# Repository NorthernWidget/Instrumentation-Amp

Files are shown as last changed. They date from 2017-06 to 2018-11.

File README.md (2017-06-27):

# Instrumentation-Amp

Breakout board for the AD623 instrumentation amplifier.

It is set up to work in either single-supply or dual-supply mode

## Single-supply mode

* Connect VC- (negative supply voltage) to GND using JP_VC- or the screw terminals

For sensors that require a simple common ground (including the reference), you will close the circuit across all of the solder jumpers:
* Connect VS- (negative voltage from device with signal to be amplified) to GND using JP_VS- or the screw terminals
* Connect Vref (reference voltage for the input signal) to GND using JP_VREF or the screw terminals

We use connect all of the jumpers to use a pyranometer.

### Dual-supply mode

We haven't had to use the board this way, but set it up to work!

* Disconnect VC- (negative supply voltage) from GND: check JP_VC- and the screw terminals
* Disconnect VS- (negative voltage from device with signal to be amplified) from GND: check JP_VS- and the screw terminals

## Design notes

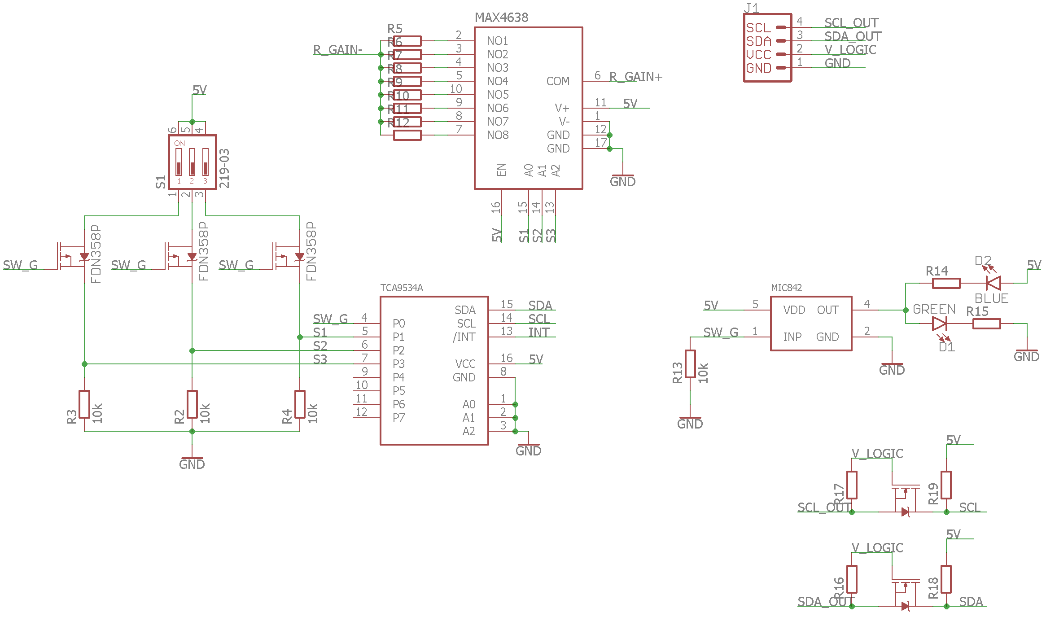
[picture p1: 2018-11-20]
PopulationDoc_pg2.png

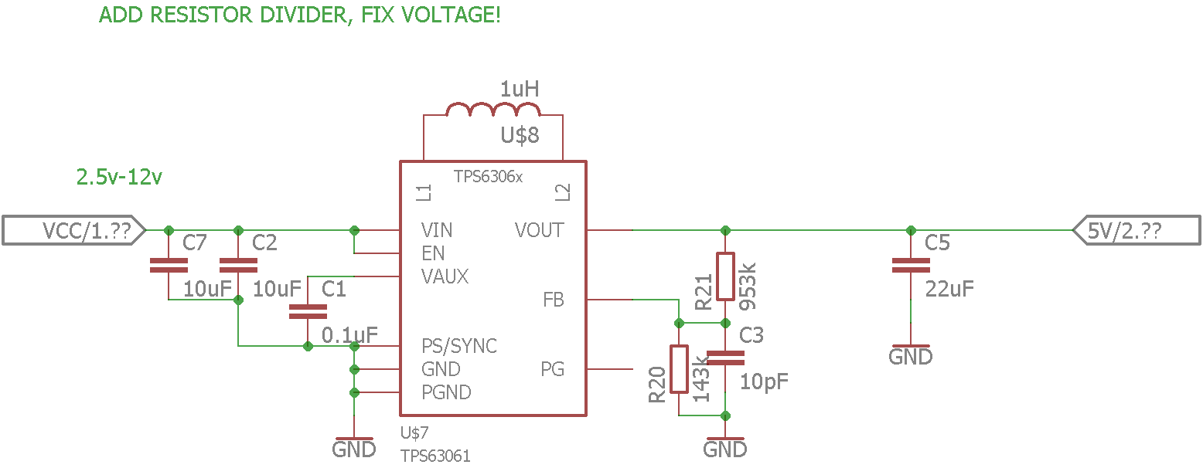
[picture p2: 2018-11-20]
PopulationDoc_pg3.png

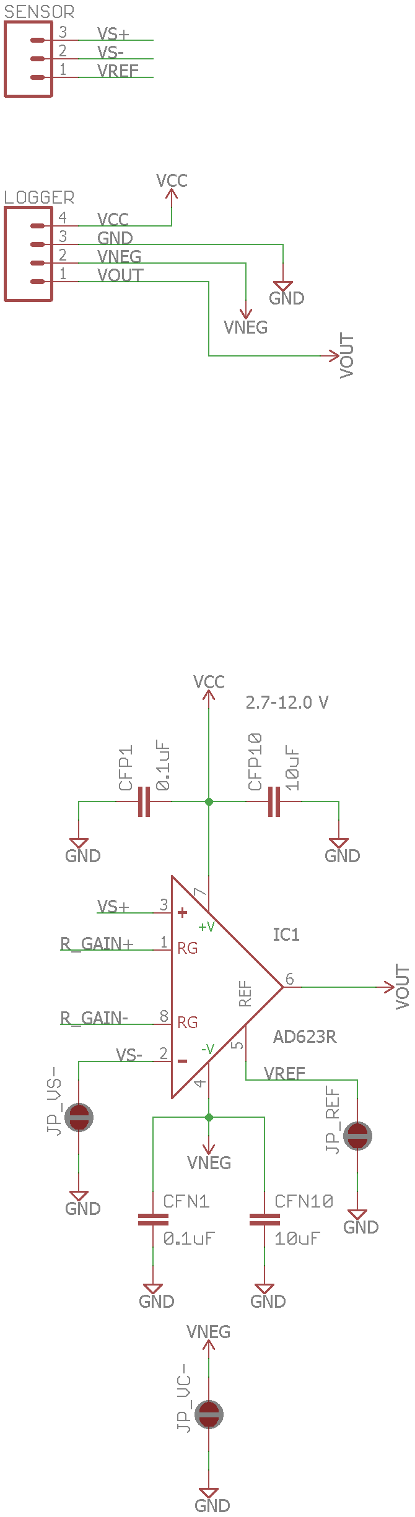
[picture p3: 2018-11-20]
PopulationDoc.png

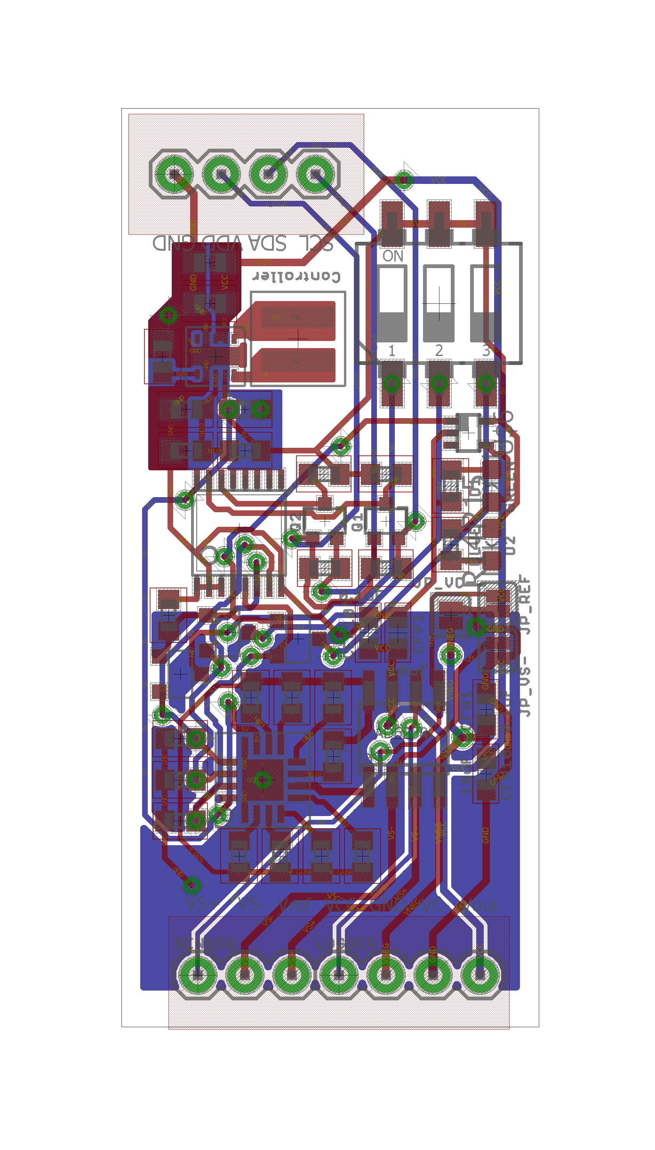
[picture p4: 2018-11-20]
PopulationBoard.png

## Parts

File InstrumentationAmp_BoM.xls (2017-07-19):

Part Number (Digi-Key) | Description | Customer Reference | Available Quantity | Backorder Quantity | Unit Price | Extended Price | Notes
AD623ARZ-RLCT-ND | IC OPAMP INSTR 800KHZ RRO 8SOIC | INSTRUMENTATION AMP | 1 | 0 | 4.55 | 4.55
 |  | Cap 10 uF 0603 | 2 | 0 |  |  | >=50V
 |  | Cap 0.1 uF 0603 | 2 | 0 |  |  | >=50V
 |  | Screw Terminal x2 0.1” |  |  |  |  | OPTIONAL
 |  | Screw Terminal x4 0.1” |  |  |  |  | OPTIONAL
 |  | Gain Resistor |  |  |  |  | USER-SELECTED

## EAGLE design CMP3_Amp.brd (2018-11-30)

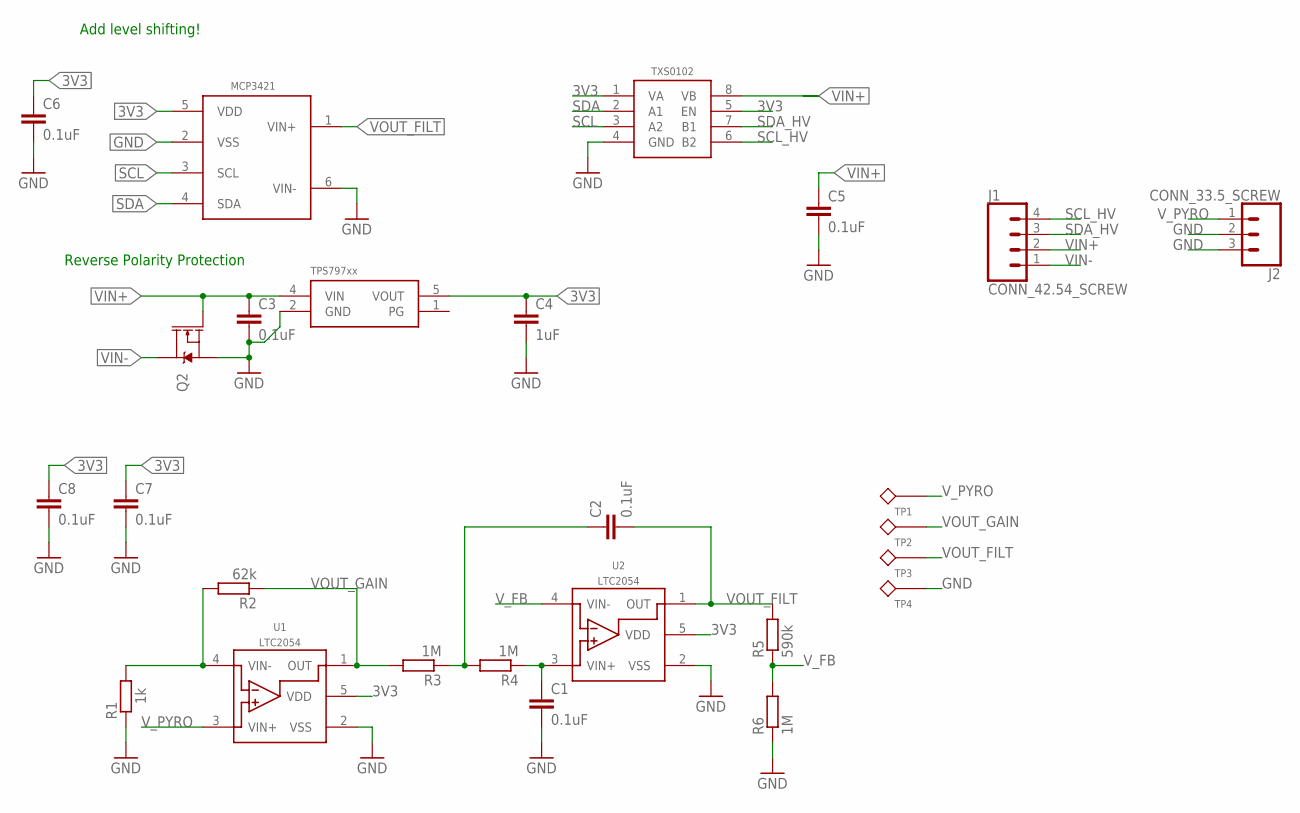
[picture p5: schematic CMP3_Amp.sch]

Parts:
C1, C2, C3: 0.1uF; C0603
C4: 1uF; C0603
C5, C6, C7, C8: 0.1uF; C0402
J1: CONN_42.54_SCREW; 1X04_SCREW
J2: CONN_33.5_SCREW; 1X03_3.5MM_SCREW
Q2: DMG3404; SOT23-3
R1: 1k; R0603
R2: 62k; R0603
R3, R4, R6: 1M; R0603
R5: 590k; R0603
TP1, TP2, TP3, TP4: TESTPOINTRCU; TESTPOINT_0603
U1, U2: LTC2054; SOT23-5
U3: MCP3421A1; SOT23-6L
U4: TXS0102DQM; DQM_R-PX2SON-N8
U5: TPS79733; DCK_R-PDSO-G5

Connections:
3V3: C4.1, C6.1, C7.1, C8.1, U1.5 (VDD), U2.5 (VDD), U3.5 (VDD), U4.1 (VA), U4.5 (EN), U5.5 (VOUT)
GND: C1.2, C3.2, C4.2, C5.2, C6.2, C7.2, C8.2, J2.2, J2.3, Q2.2 (S), R1.1, R6.1, TP4.1, U1.2 (VSS), U2.2 (VSS), U3.2 (VSS), U3.6 (VIN-), U4.4 (GND), U5.2 (GND)
unnamed: R1.2, R2.2, U1.4 (VIN-)
unnamed: C2.1, R3.1, R4.2
unnamed: C1.1, R4.1, U2.3 (VIN+)
SCL: U3.3 (SCL), U4.3 (A2)
SCL_HV: J1.4, U4.6 (B2)
SDA: U3.4 (SDA), U4.2 (A1)
SDA_HV: J1.3, U4.7 (B1)
VIN+: C3.1, C5.1, J1.2, Q2.1 (G), U4.8 (VB), U5.4 (VIN)
VIN-: J1.1, Q2.3 (D)
VOUT_FILT: C2.2, R5.2, TP3.1, U2.1 (OUT), U3.1 (VIN+)
VOUT_GAIN: R2.1, R3.2, TP2.1, U1.1 (OUT)
V_FB: R5.1, R6.2, U2.4 (VIN-)
V_PYRO: J2.1, TP1.1, U1.3 (VIN+)

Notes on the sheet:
Reverse Polarity Protection
Add level shifting!

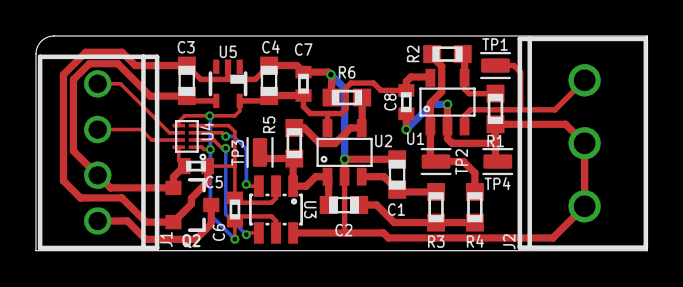
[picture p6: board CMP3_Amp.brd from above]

Board: 2 copper layers, 34.0 x 11.9 mm, 26 parts (0 on the bottom side), 15 nets.

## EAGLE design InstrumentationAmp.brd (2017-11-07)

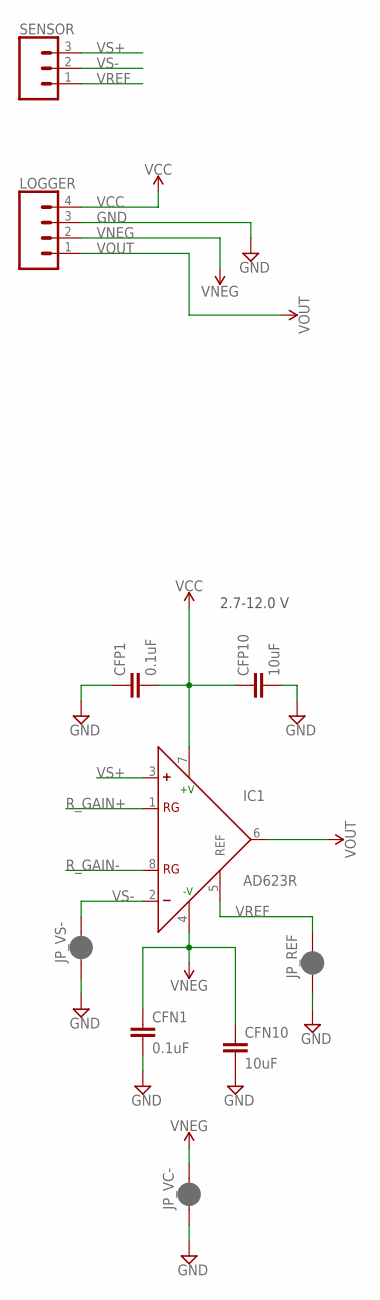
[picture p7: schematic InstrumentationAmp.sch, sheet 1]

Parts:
CFN1: 0.1uF; 0603
CFN10: 10uF; C0805
CFP1: 0.1uF; 0603
CFP10: 10uF; C0805
IC1: AD623R; SO8
JP_REF: JUMPER-SMT_2_NC_PASTE_SILK; SMT-JUMPER_2_NC_PASTE_SILK
JP_VC-: JUMPER-SMT_2_NC_PASTE_SILK; SMT-JUMPER_2_NC_PASTE_SILK
JP_VS-: JUMPER-SMT_2_NC_PASTE_SILK; SMT-JUMPER_2_NC_PASTE_SILK
LOGGER: CONN_04; 1X04
SENSOR: CONN_03; 1X03

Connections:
GND: CFN1.2, CFN10.2, CFP1.1, CFP10.2, JP_REF.1, JP_VC-.1, JP_VS-.1, LOGGER.3; also elsewhere on the board
R_GAIN+: IC1.1 (RG); also elsewhere on the board
R_GAIN-: IC1.8 (RG); also elsewhere on the board
VCC: CFP1.2, CFP10.1, IC1.7 (+V), LOGGER.4; also elsewhere on the board
VNEG: CFN1.1, CFN10.1, IC1.4 (-V), JP_VC-.2, LOGGER.2
VOUT: IC1.6 (OUT), LOGGER.1
VREF: IC1.5 (REF), JP_REF.2, SENSOR.1
VS+: IC1.3 (+), SENSOR.3
VS-: IC1.2 (-), JP_VS-.2, SENSOR.2

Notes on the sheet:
2.7-12.0 V

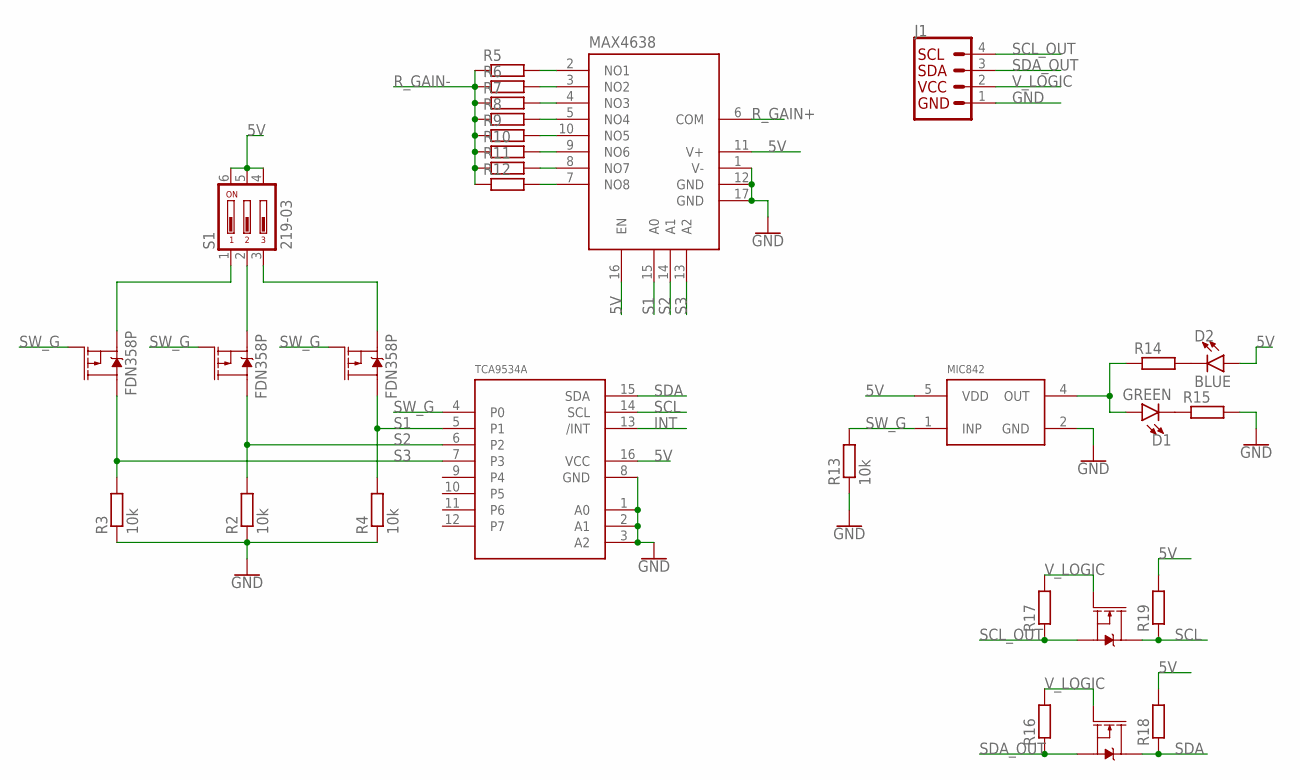
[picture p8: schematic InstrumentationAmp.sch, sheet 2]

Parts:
D1: GREEN; LED-0603
D2: BLUE; LED-0603
J1: I2C_STANDARD; 1X04
Q1, Q2: 310mA/60V/1.6Ω; SOT323
R2, R3, R4, R13: 10k; R0603
R5, R6, R7, R8, R9, R10, R11, R12, R14, R15, R16, R17, R18, R19: R-EU_R0603; R0603
S1: 219-03; CTS-219-03
U$1: MAX4638; TQFN16
U$2: TCA9534A; TSSOP16
U$3, U$4, U$5: FDN358P; SSOT-3
U$6: MIC842; DCK_R-PDSO-G5

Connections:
5V: D2.A, R18.2, R19.2, S1.4, S1.5, S1.6, U$1.11 (V+), U$1.16 (EN), U$2.16 (VCC), U$6.5 (VDD); also elsewhere on the board
GND: J1.1, R2.1, R3.1, R4.1, R13.1, R15.2, U$1.1 (V-), U$1.12 (GND), U$1.17 (GND), U$2.1 (A0), U$2.2 (A1), U$2.3 (A2), U$2.8 (GND), U$6.2 (GND); also elsewhere on the board
INT: U$2.13 (/INT)
unnamed: S1.2, U$4.2 (S)
unnamed: D2.C, R14.2
unnamed: S1.3, U$5.2 (S)
unnamed: S1.1, U$3.2 (S)
unnamed: R5.2, U$1.2 (NO1)
unnamed: R6.2, U$1.3 (NO2)
unnamed: R7.2, U$1.4 (NO3)
unnamed: R8.2, U$1.5 (NO4)
unnamed: R9.2, U$1.10 (NO5)
unnamed: R10.2, U$1.9 (NO6)
unnamed: R11.2, U$1.8 (NO7)
unnamed: R12.2, U$1.7 (NO8)
unnamed: D1.C, R15.1
unnamed: D1.A, R14.1, U$6.4 (OUT)
R_GAIN+: U$1.6 (COM); also elsewhere on the board
R_GAIN-: R5.1, R6.1, R7.1, R8.1, R9.1, R10.1, R11.1, R12.1; also elsewhere on the board
S1: R4.2, U$1.15 (A0), U$2.5 (P1), U$5.3 (D)
S2: R2.2, U$1.14 (A1), U$2.6 (P2), U$4.3 (D)
S3: R3.2, U$1.13 (A2), U$2.7 (P3), U$3.3 (D)
SCL: Q2.3 (D), R19.1, U$2.14 (SCL)
SCL_OUT: J1.4, Q2.2 (S), R17.1
SDA: Q1.3 (D), R18.1, U$2.15 (SDA)
SDA_OUT: J1.3, Q1.2 (S), R16.1
SW_G: R13.2, U$2.4 (P0), U$3.1 (G), U$4.1 (G), U$5.1 (G), U$6.1 (INP)
V_LOGIC: J1.2, Q1.1 (G), Q2.1 (G), R16.2, R17.2

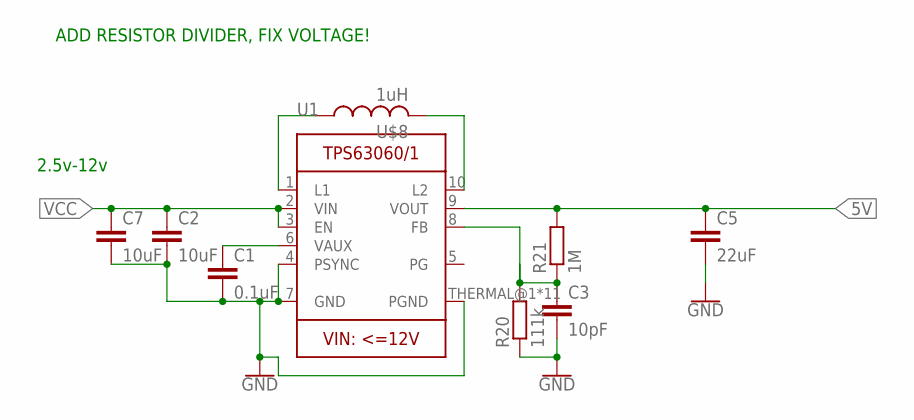
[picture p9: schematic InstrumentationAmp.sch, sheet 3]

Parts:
C1: 0.1uF; C0603
C2, C7: 10uF; C0805
C3: 10pF; C0603
C5: 22uF; C0805
R20: 111k; R0603
R21: 1M; R0603
U1: TPS63061; PWSON-N10
U$8: 1uH; WE-MAIA(4.1X4.1)

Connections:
5V: C5.1, R21.2, U1.9 (VOUT); also elsewhere on the board
GND: C1.2, C2.2, C3.2, C5.2, C7.2, R20.1, U1.4 (PSYNC), U1.7 (GND), U1.THERMAL@1 (PGND), U1.THERMAL@5 (PGND), U1.THERMAL@6 (PGND), U1.THERMAL@7 (PGND), U1.THERMAL@8 (PGND), U1.THERMAL@9 (PGND), U1.THERMAL@10 (PGND), U1.THERMAL@11 (PGND), U1.THERMAL@12 (PGND), U1.THERMAL@13 (PGND), U1.THERMAL@14 (PGND); also elsewhere on the board
unnamed: U1.1 (L1), U$8.P$1 (1)
unnamed: C3.1, R20.2, R21.1, U1.8 (FB)
unnamed: U1.10 (L2), U$8.P$2 (2)
unnamed: C1.1, U1.6 (VAUX)
VCC: C2.1, C7.1, U1.2 (VIN), U1.3 (EN); also elsewhere on the board

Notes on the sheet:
2.5v-12v
ADD RESISTOR DIVIDER, FIX VOLTAGE!

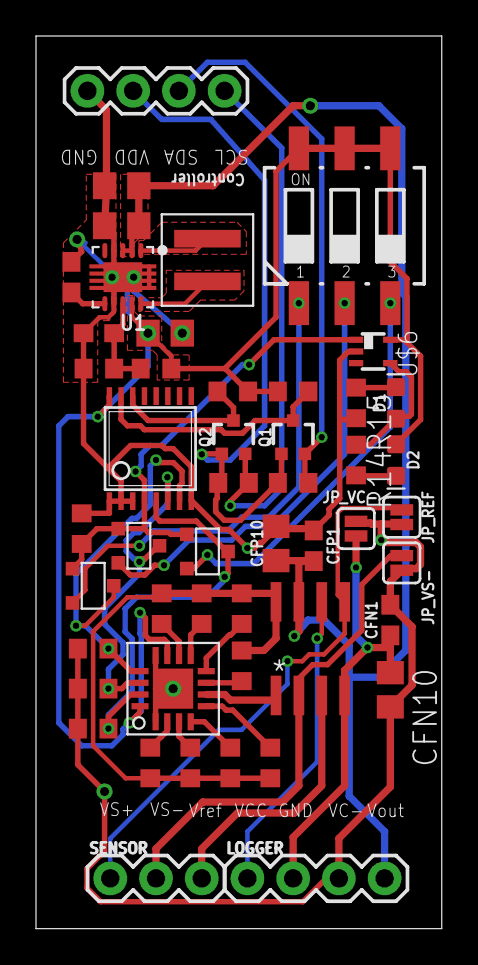
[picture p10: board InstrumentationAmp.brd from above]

Board: 2 copper layers, 22.5 x 49.6 mm, 49 parts (0 on the bottom side), 37 nets.

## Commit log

2016-07-19 Version one of instrumentation amplifier
    [Instrumentation amp.brd, Instrumentation amp.sch]
2016-07-20 Improved tracing and changes for OSH Park compliance
    [Instrumentation amp.brd]
2016-08-11 Changed ground, added ground fill to top layer
    [Instrumentation amp BOM.xls, Instrumentation amp.brd]
2017-06-27 AD623R Redesign
    [Instrumentation amp.brd, Instrumentation amp.sch, InstrumentationAmp.brd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]
2017-06-27 Rough BoM
    [Instrumentation amp BOM.xls, InstrumentationAmp_BoM.xls]
2017-06-27 Names match README; connect Vref
    [InstrumentationAmp.brd, InstrumentationAmp.sch]
2017-06-27 ERC, DRC
    [InstrumentationAmp.brd, InstrumentationAmp.sch]
2017-06-27 Pin 1 marker
    [InstrumentationAmp.brd]
2017-07-18 Initial layout of Amp 2.0
    Changed schematic to add on board buck-boost converter, mux to control gain, and I2C IO expander to allow gain to be controlled via I2C. Preliminary layout complete, ready for verification
    [InstrumentationAmp.brd, InstrumentationAmp.sch, InstrumentationAmp_BoM.xls]
2017-07-19 Fixed spacing for screw terminals, ready for final check
    Moved the screw terminals and silk screen to support screw terminal sizes, fixed one air wire on board layout, ready for final check before ordering
    [InstrumentationAmp.brd, InstrumentationAmp_BoM.xls]
2017-09-05 upload gerbers
    [InstrumentationAmp.GBL, InstrumentationAmp.GBO, InstrumentationAmp.GBS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]
2017-09-26 Added layer 112 tsilk
    [InstrumentationAmp.GTO]
2017-10-26 Made Edits from 1st round of board testing
    Flipped direciton of PFETs, fixed switch mode regulator package, changed capacitor sizes, chained set resistor values, etc. Verification still required that all changes are made
    [InstrumentationAmp.brd, InstrumentationAmp.sch]
2017-11-06 Fixed some DRC errors, added to ground plane
    Made additions to power ground plane, fixed releveant DRC errors, ready for checking
    [InstrumentationAmp.brd]
2017-11-06 Added Silkscreen model ID
    [InstrumentationAmp.brd]
2017-11-07 added gerber files
    [InstrumentationAmp.GBL, InstrumentationAmp.GBO, InstrumentationAmp.GBS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]
2017-11-07 changes to header and silkscreen labels
    [InstrumentationAmp.brd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]
2017-11-07 move brd file out of gerber folder
    [InstrumentationAmp.brd]
2018-11-20 Board assembly photos for inst amp
2018-11-20 Added dedicated CMP3
    Added an updated digital interface amplifier specifically designed for the Kipp and Zonen CMP3
    [CMP3_Amp.brd, CMP3_Amp.sch]
2018-11-20 Initial layout of CMP3 Amp
    Layout of CMP3 amp complete, requires review and gerber generation before being sent to fab
    [CMP3_Amp.brd, CMP3_Amp.sch]
2018-11-20 Updated silk screen
    [CMP3_Amp.brd]
2018-11-20 Added Gerbers
2018-11-26 Generated Gerbers, Minor Updates
    [CMP3_Amp.brd]
2018-11-30 Updated part numbers for CMP3 Amp
    Updated part numbers for CMP3 amp and made changes to the CMP3 amp simulation
    [CMP3_Amp.brd, CMP3_Amp.sch]

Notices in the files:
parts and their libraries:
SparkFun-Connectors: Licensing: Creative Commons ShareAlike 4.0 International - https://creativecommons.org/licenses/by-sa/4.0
